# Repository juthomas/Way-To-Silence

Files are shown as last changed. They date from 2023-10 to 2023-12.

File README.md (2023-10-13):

# WAY TO SILENCE

## Goals
- Develop a module based on the ESP32, designed to read audio tracks stored on an SD card and to transmit them through a speaker output. Users should be able to adjust the parameters of these audio tracks, such as volume and balance, via an intuitive and easily accessible web interface. Furthermore, control over the tracks and playback settings via UDP signals is essential. This interface will provide users with the opportunity to customize their listening experience and adjust settings to their preferences. It will also ensure quick and efficient communication with the module through the UDP protocol. In addition, effective battery management is crucial to ensure the module's durability and optimal performance.

## 3D Render
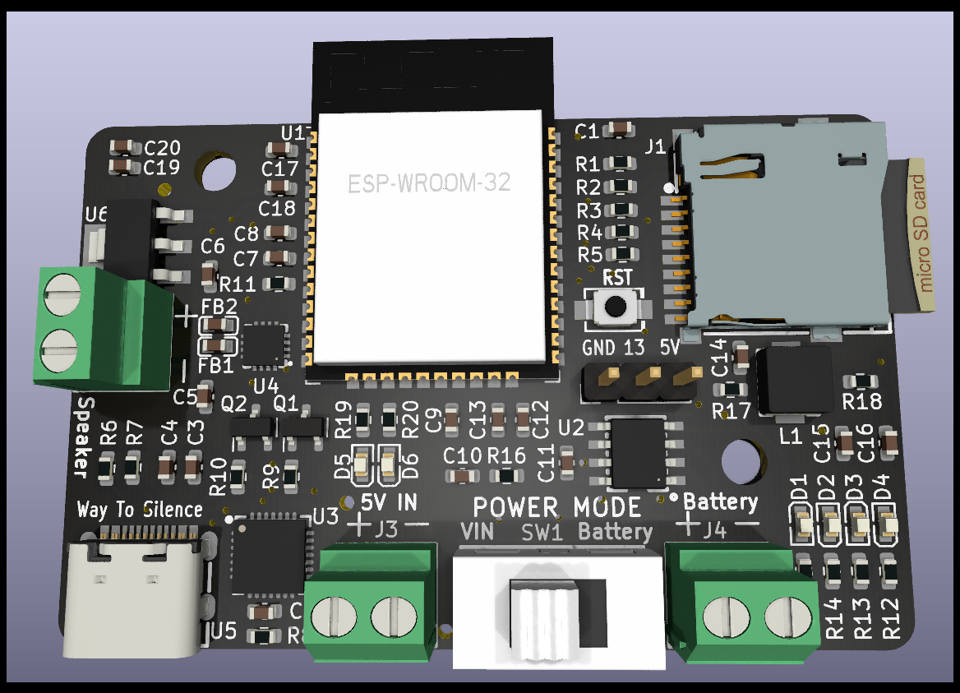
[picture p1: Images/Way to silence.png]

## Schematics

- [Link to pdf](https://github.com/juthomas/Way-To-Silence/blob/main/Schematics%20PDF/Way%20to%20silence.pdf)

## Bill Of Materials

- [Link to IBOM](https://juthomas.github.io/Way-To-Silence/)
## Components
- [I2S Amplifier Module MAX98357A](https://www.lcsc.com/product-detail/Audio-Power-OpAmps_Analog-Devices-Inc-Maxim-Integrated-MAX98357AETE-T_C910544.html) € 0.7886

- [SD Card Connector](https://jlcpcb.com/partdetail/gswitch-GT_TF003_H018502/C5155564) € 0.1553

- [ESP32 4Mb Flash](https://www.lcsc.com/product-detail/WiFi-Modules_Espressif-Systems-ESP32-WROOM-32-N4_C82899.html) € 2.5764

- [ESP32 8Mb Flash](https://www.lcsc.com/product-detail/WiFi-Modules_Espressif-Systems-ESP32-WROOM-32-N8_C529582.html) € 2.9722

- [ESP32 16Mb Flash](https://lcsc.com/product-detail/WiFi-Modules_Espressif-Systems-ESP32-WROOM-32-N16_C529581.html) € 3.3920

- [CP2102](https://www.lcsc.com/product-detail/USB-ICs_SILICON-LABS-CP2102-GMR_C6568.html) € 2.0075

- [CH340C](https://www.lcsc.com/product-detail/USB-ICs_WCH-Jiangsu-Qin-Heng-CH340C_C84681.html) € 0.45

- [BMS SM5308](https://www.lcsc.com/product-detail/Battery-Management-ICs_HICHON-SM5308_C5345582.html) € 0.2758
- [USB C Connector](https://jlcpcb.com/partdetail/Dealon-USB_TYPE_C018/C2927038) $ 0.0479
- [3.3V Regulator](https://www.lcsc.com/product-detail/Linear-Voltage-Regulators-LDO_UMW-Youtai-Semiconductor-Co-Ltd-AMS1117-3-3_C347222.html) € 0.0398

- [Bornier 3.5mm](https://www.lcsc.com/product-detail/Screw-terminal_Ningbo-Xinlaiya-Elec-XY350V-3-5-2P_C784942.html) € 0.1065
- [2.2uH Inductance](https://www.lcsc.com/product-detail/Inductors-SMD_KOHERelec-MDA4020-2R2M_C2847469.html) € 0.7154
- [1uH Inductance](https://www.lcsc.com/product-detail/Inductors-SMD_KOHERelec-MDA4020-1R0M_C2847468.html#) € 0.7287
- [Battery Switch](https://jlcpcb.com/partdetail/XkbConnectivity-SS12D10L3/C319013) € 0.8814
- [Reset Button](https://jlcpcb.com/partdetail/Xunpu-TS_1088R02026/C455280) € 0.0448

- [4.7nF Capacitor](https://jlcpcb.com/partdetail/55004-0603B472K500NT/C53987) € 0.0025
- [4.7uF Capacitor](https://jlcpcb.com/partdetail/20375-CL10A475KO8NNNC/C19666) € 0.0095
- [10uF Capacitor](https://jlcpcb.com/partdetail/MurataElectronics-GRM188R60J106ME47D/C77041) € 0.0085	
- [22uF Capacitor](https://jlcpcb.com/partdetail/60514-CL10A226MQ8NRNC/C59461) € 0.0085
- [100nF Capacitor](https://jlcpcb.com/partdetail/Yageo-CC0603KRX7R9BB104/C14663) € 0.0022
- [220pF Capacitor](https://jlcpcb.com/partdetail/1955-CL10B221KB8NNNC/C1603) € 0.0055
- [0Ω Resistor](https://jlcpcb.com/partdetail/21903-0603WAF0000T5E/C21189) € 0.0011
- [100mΩ Resistor](https://jlcpcb.com/partdetail/112253-0603WAF100LT5E/C111027) € 0.0039
- [500mΩ Resistor](https://jlcpcb.com/partdetail/Fojan-FRL0603FR500TS/C2934253) € 0.0031
- [1Ω Resistor](https://jlcpcb.com/partdetail/25955-0603WAJ010JT5E/C25212) € 0.0009
- [1kΩ Resistor](https://jlcpcb.com/partdetail/21904-0603WAF1001T5E/C21190) € 0.0006

- [5.11kΩ Resistor](https://jlcpcb.com/partdetail/419038-TC0350B5111T5E/C425414) € 0.0167
- [10kΩ Resistor](https://jlcpcb.com/partdetail/26547-0603WAF1002T5E/C25804) € 0.0009
- [1MΩ Resistor](https://jlcpcb.com/partdetail/23662-0603WAF1004T5E/C22935) € 0.0011
- [Red LED](https://jlcpcb.com/partdetail/85432-NCD0603R1/C84263) € 0.0078
- [Yellow LED](https://jlcpcb.com/partdetail/85437-NCD0603Y1/C84268) € 0.0111
- [Ferrite Bead](https://jlcpcb.com/partdetail/373749-CBW160808U470T/C394474) € 0.0030
- [Transistor](https://jlcpcb.com/partdetail/Shikues-BC817/C475629) € 0.0150

## Tools used

- [KiCad](https://www.kicad.org/)
- [KiCad Fabrication Toolkit Plugin](https://github.com/bennymeg/JLC-Plugin-for-KiCad)
- [KiCad Interactive Html Bom Plugin](https://github.com/openscopeproject/InteractiveHtmlBom)
- [LCSC](https://www.lcsc.com/)
- [JCLPCB](https://jlcpcb.com/)

- [EasyEDA to KiCad](https://wokwi.com/tools/easyeda2kicad)

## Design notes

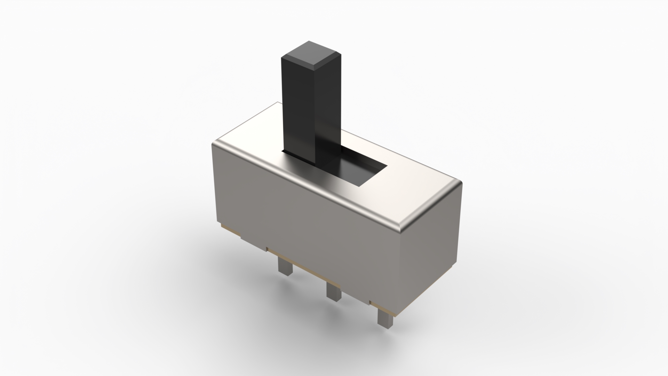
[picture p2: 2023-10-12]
3D Models/Switch/Untitled Project.jpg

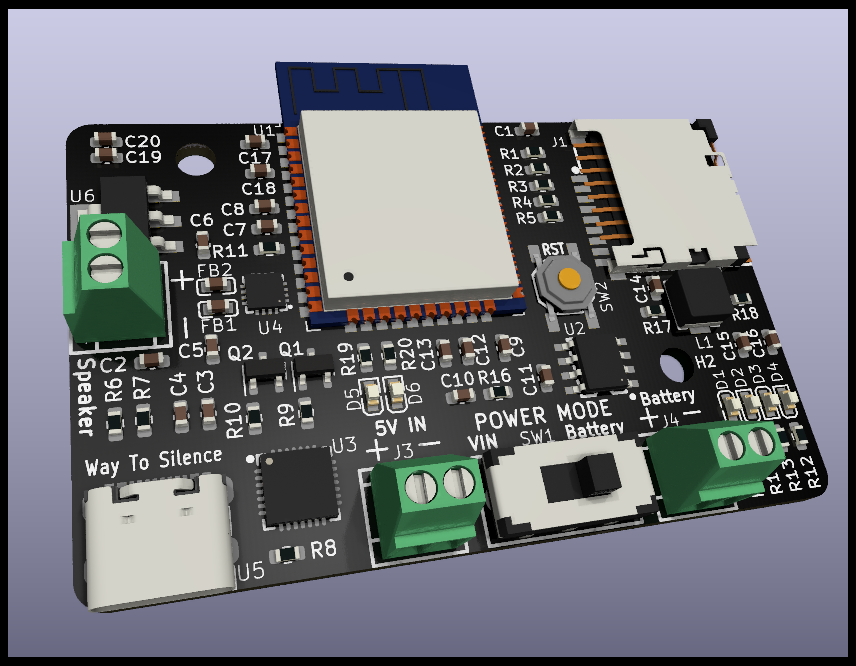
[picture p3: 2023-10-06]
Way to silence/Way to silence, Non-routed.png

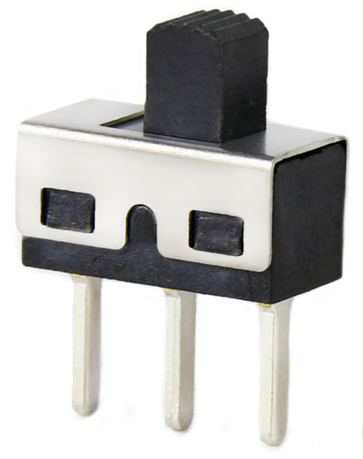
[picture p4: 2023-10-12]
3D Models/Switch Button/SS-12D10.png

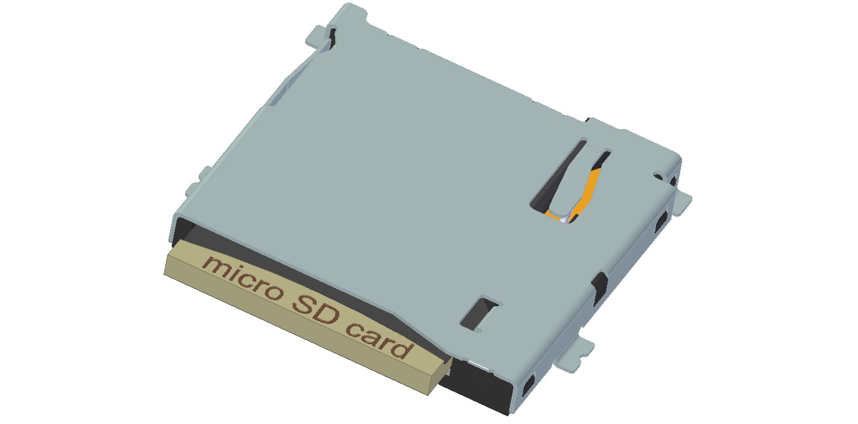
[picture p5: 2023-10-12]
3D Models/Micro SD/Micro_SD_Card_and_Holder.jpg

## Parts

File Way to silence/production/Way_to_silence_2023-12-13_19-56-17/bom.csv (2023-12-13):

Designator | Footprint | Quantity | Value | LCSC Part #
C1, C18, C19, C2, C3, C7 | 0603 | 6 | 100nF | C14663
C10, C12, C17, C20, C21, C8, C9 | 0603 | 7 | 10uF | C77041
C11, C16 | 0603 | 2 | 22uF | C59461
C4 | 0603 | 1 | 4.7uF | C19666
C5, C6 | 0603 | 2 | 220pF | C1603
D1, D2, D3, D4, D5, D6 | LED_0603 | 6 | LED | C84268
FB1, FB2 | FB_0603 | 2 | FerriteBead | C394474
J1 | SD_Card_Connector | 1 | SD Card Connector | C5155564
J2 | Screw_Terminal_3.5 | 1 | Amplificator_Terminal | C784942
J3 | Screw_Terminal_3.5 | 1 | 5V_Terminal | C784942
J4 | Screw_Terminal_3.5 | 1 | Battery_Terminal | C784942
J6 | PinHeader_1x04_P2.54mm_Vertical | 1 | Conn_01x04_Pin
L1 | Inductor-0630LR | 1 | 2.2UH | C5189746
Q1, Q2 | SOT-23 | 2 | BC817 | C475629
R1, R10, R17, R2, R21, R3, R4, R5, R9 | 0603 | 9 | 10K | C25804
R11, R8 | 0603 | 2 | 1M | C22935
R12, R13, R14, R15 | 0603 | 4 | 0 | C21189
R16 | 0603 | 1 | 1R | C25212
R19, R20 | 0603 | 2 | 1K | C21190
R6, R7 | 0603 | 2 | 5.11K | C425414
SW1 | SW_SPDT | 1 | SW_SPDT | C319013
SW2, SW3 | SW_SPST | 2 | SW_SPST | C455280
U1 | ESP32-WROOM-32 | 1 | ESP32-WROOM-32-N16 | C529581
U2 | SM5308 | 1 | SM5308 | C5345582
U3 | CP2102 | 1 | CP2102-GMR | C6568
U4 | MAX98357 | 1 | MAX98357AETE+T | C910544
U5 | USB_C_Receptacle | 1 | USB-TYPE-C-018 | C2927038
U6 | AMS1117CD-3.3 | 1 | AMS1117CD-3.3 | C347222

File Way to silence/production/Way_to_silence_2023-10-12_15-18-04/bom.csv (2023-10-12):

Designator | Footprint | Quantity | Value | LCSC Part #
C1, C18, C19, C2, C3, C7 | 0603 | 6 | 100nF | C14663
C10, C17, C20, C8, C9 | 0603 | 5 | 10uF | C77041
C11, C12, C13, C15, C16 | 0603 | 5 | 22uF | C59461
C14 | 0603 | 1 | 4.7nF | C53987
C4 | 0603 | 1 | 4.7uF | C19666
C5, C6 | 0603 | 2 | 220pF | C1603
D1, D2, D3, D4, D5, D6 | LED_0603 | 6 | LED | C84268
FB1, FB2 | FB_0603 | 2 | FerriteBead | C394474
J1 | SD_Card_Connector | 1 | SD Card Connector | C5155564
J2 | Screw_Terminal_3.5 | 1 | Amplificator_Terminal | C784942
J3 | Screw_Terminal_3.5 | 1 | 5V_Terminal | C784942
J4 | Screw_Terminal_3.5 | 1 | Battery_Terminal | C784942
J5 | PinHeader_1x03_P2.54mm_Vertical | 1 | LEDS Port
L1 | Inductor | 1 | 1UH | C2847468
Q1, Q2 | SOT-23 | 2 | BC817 | C475629
R1, R10, R2, R3, R4, R5, R9 | 0603 | 7 | 10K | C25804
R11, R8 | 0603 | 2 | 1M | C22935
R12, R13, R14, R15 | 0603 | 4 | 0 | C21189
R16 | 0603 | 1 | 0.5R | C2934253
R17 | 0603 | 1 | 1R | C25212
R18 | 0603 | 1 | 0.1R | C111027
R19, R20 | 0603 | 2 | 1K | C21190
R6, R7 | 0603 | 2 | 5.11K | C425414
SW1 | SW_SPDT | 1 | SW_SPDT | C319013
SW3 | SW_SPST | 1 | SW_SPST | C455280
U1 | ESP32-WROOM-32 | 1 | ESP32-WROOM-32-N16 | C529581
U2 | SM5308 | 1 | SM5308 | C5345582
U3 | CP2102 | 1 | CP2102-GMR | C6568
U4 | MAX98357 | 1 | MAX98357AETE+T | C910544
U5 | USB_C_Receptacle | 1 | USB-TYPE-C-018 | C2927038
U6 | AMS1117CD-3.3 | 1 | AMS1117CD-3.3 | C347222

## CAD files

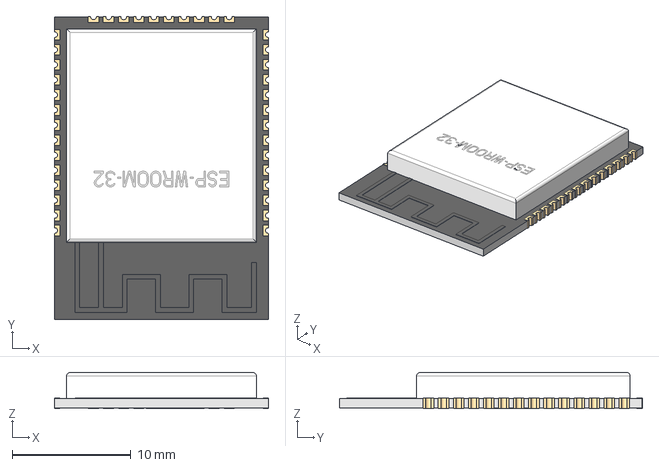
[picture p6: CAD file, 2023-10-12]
3D Models/ESP 32/KiCAD-ESP-WROOM-32.step
18.1 x 25.5 x 3.04 mm

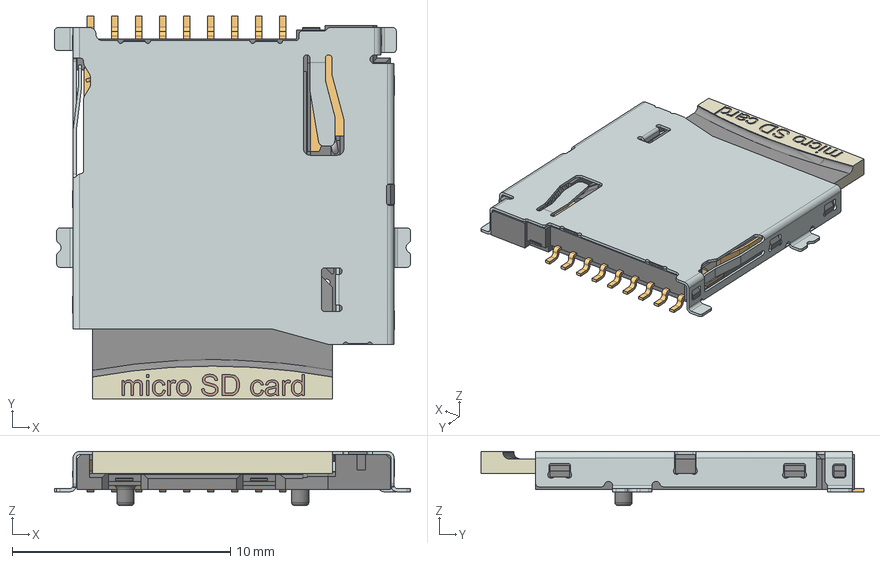
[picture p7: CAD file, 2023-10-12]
3D Models/Micro SD/Micro_SD_Card_and_Holder.stp
16.3 x 17.5 x 2.48 mm
693071020811_Housing
693071020811_Guide
693071020811_Spring
693071020811_Contact
693071020811_Hook
693071020811_Agraphe
693071020811_Shielding
MicroSD

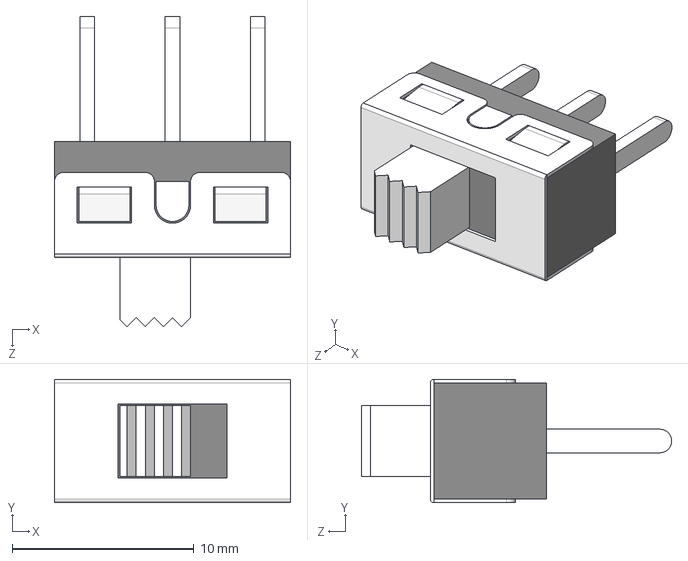
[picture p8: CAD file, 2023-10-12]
3D Models/Switch Button/SS-12D10L4.STEP
13.0 x 6.80 x 17.1 mm

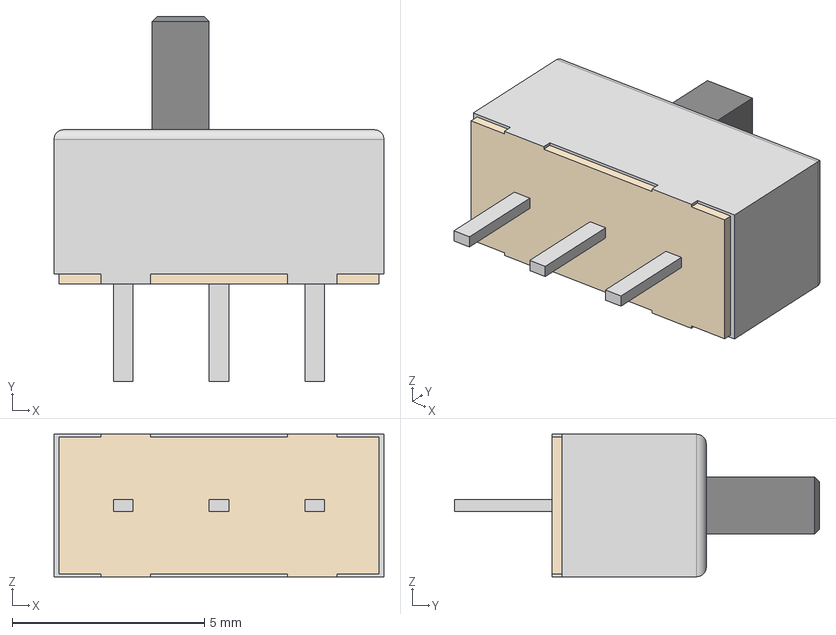
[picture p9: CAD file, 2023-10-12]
3D Models/Switch/Selector Switch - SS12D00.stp
8.59 x 9.50 x 3.71 mm

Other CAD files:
3D Models/Switch Button/SS-12D10L4.SLDPRT
3D Models/Switch/Selector Switch - SS12D00.SLDPRT

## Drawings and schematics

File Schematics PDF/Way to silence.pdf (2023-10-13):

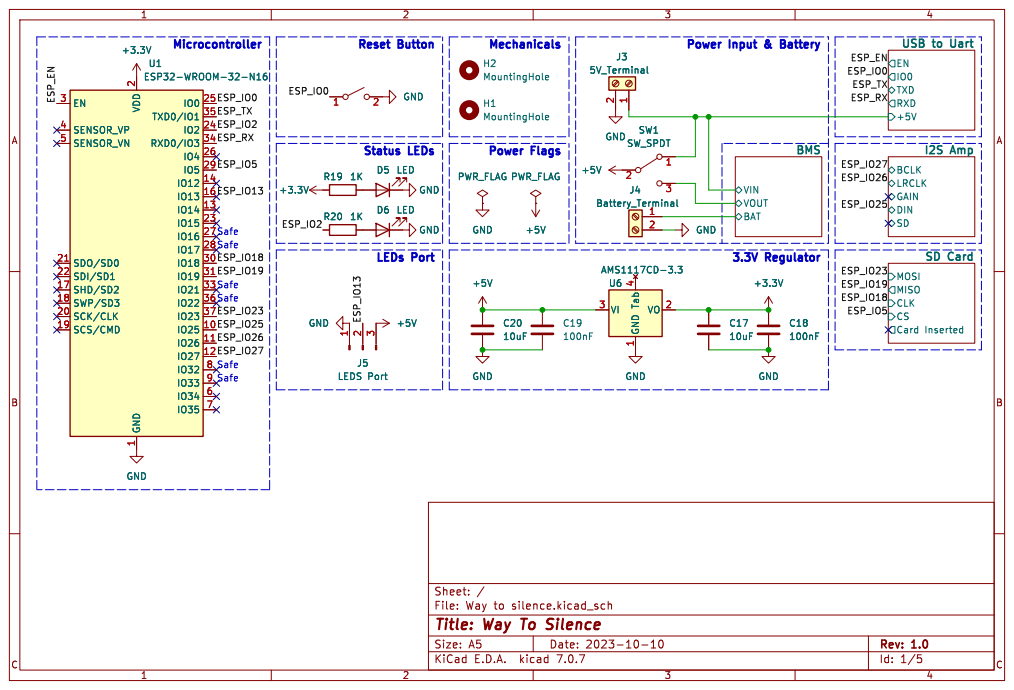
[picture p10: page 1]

2 SCK/CLK 20 SDO/SD0 21 SDI/SD1 22

Card Inserted CSCLK MOSI SD Card

Id: 1/5 Title: Way To Silence

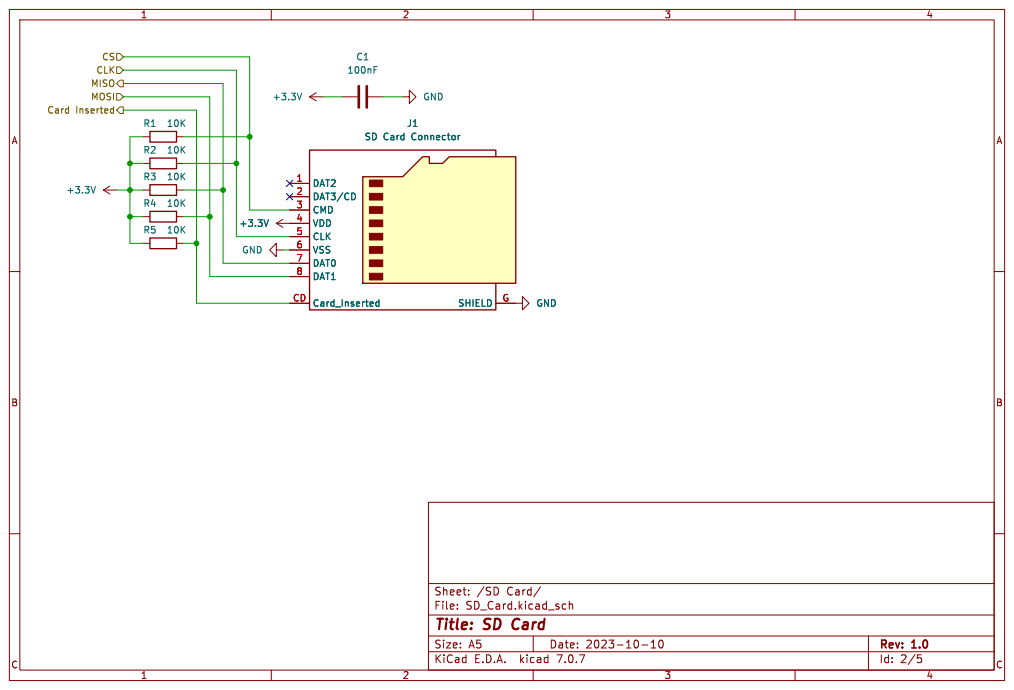
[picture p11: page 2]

J1 SD Card Connector MISO

Id: 2/5 Title: SD Card

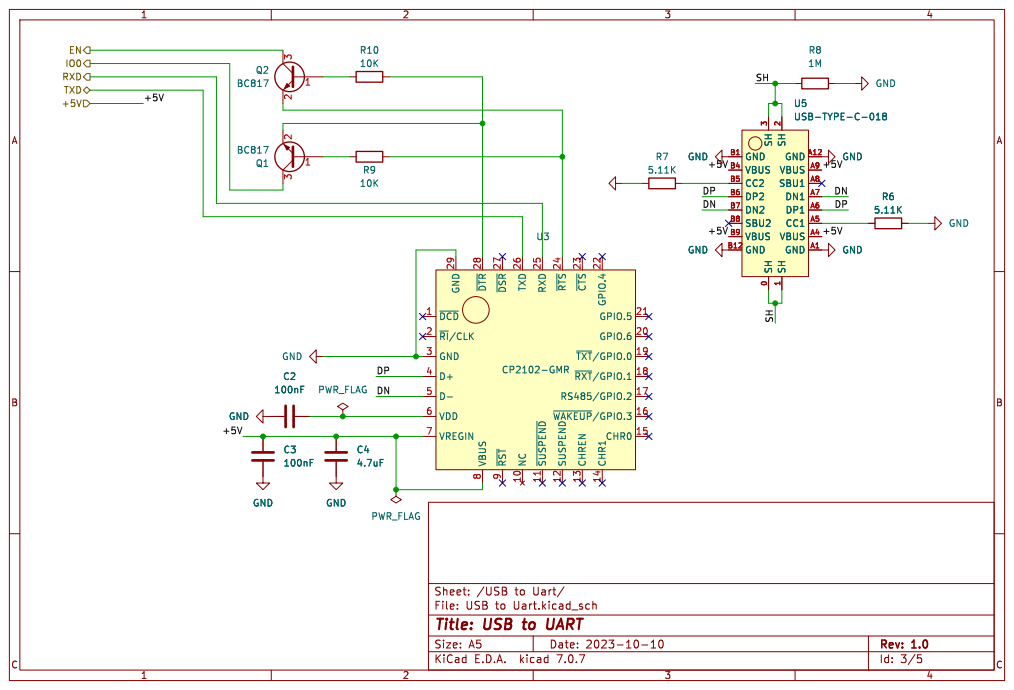
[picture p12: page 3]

3 GND A1 GND A12 VBUS A4 CC1 A5 DP1 A6 DN1 A7 SBU1 A8 VBUS A9 GND B1 GND B12 VBUS B4 CC2 B5 DP2 B6 DN2 B7 SBU2 B8 VBUS B9 U5 USB-TYPE-C-018 GND GND

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

Id: 3/5 Title: USB to UART

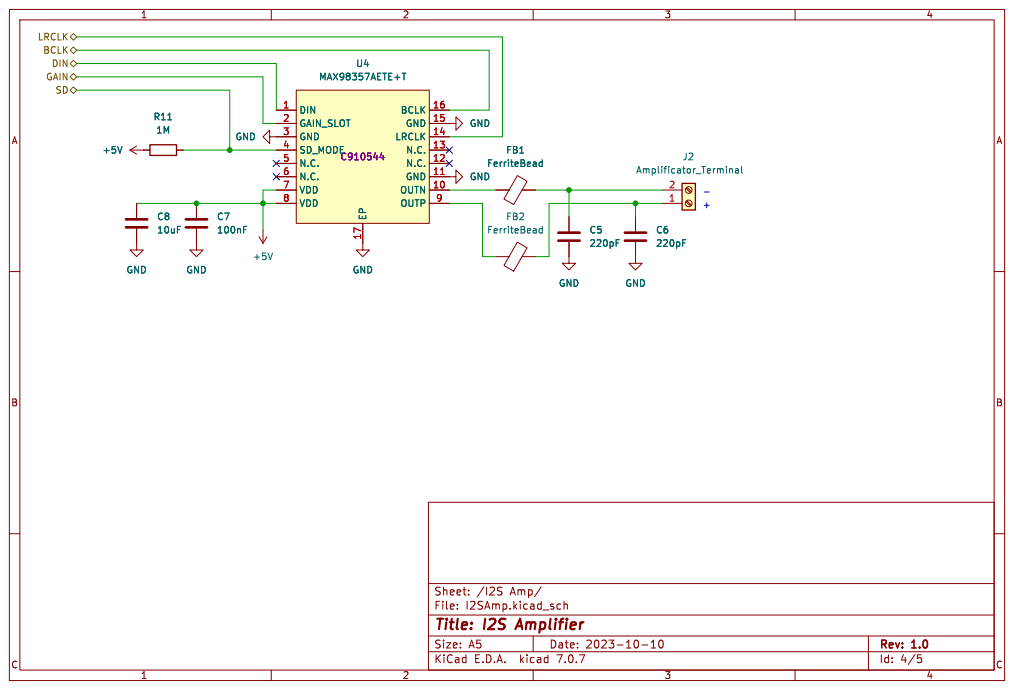
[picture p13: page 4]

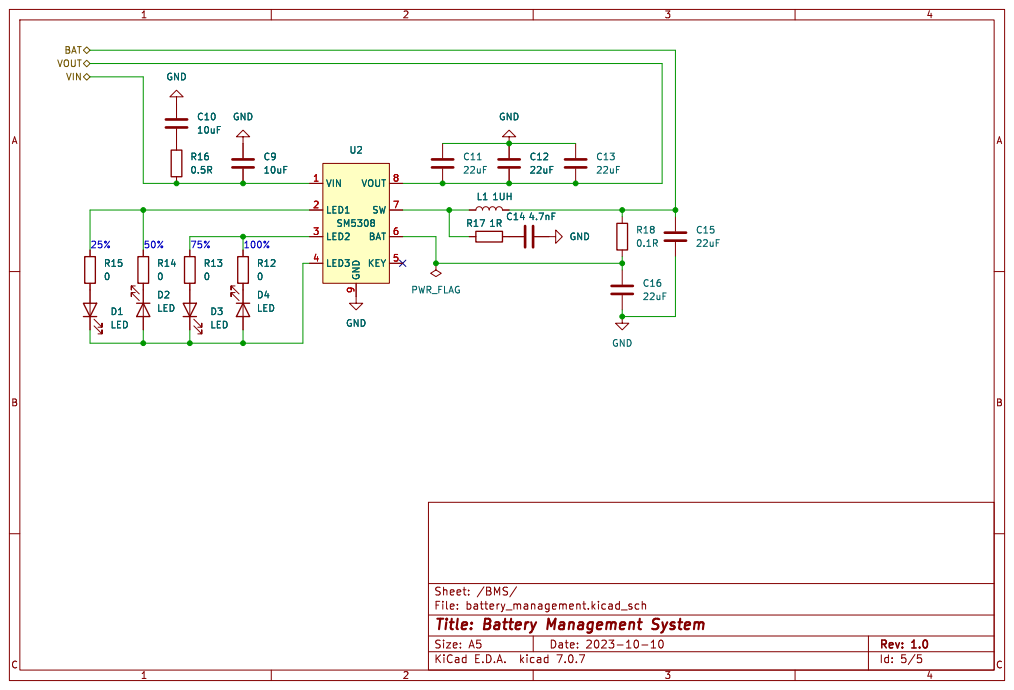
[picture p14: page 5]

Id: 5/5 Title: Battery Management System

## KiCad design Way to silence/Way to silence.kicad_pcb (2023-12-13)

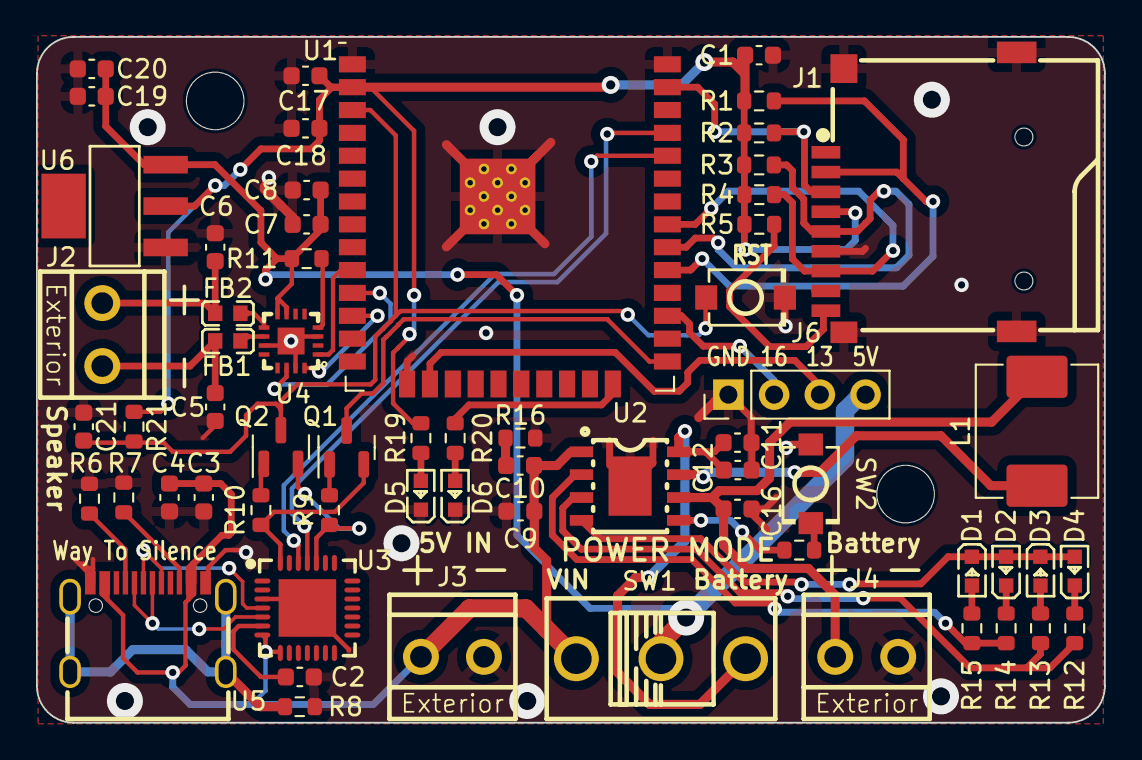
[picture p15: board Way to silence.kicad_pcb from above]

Board: 2 copper layers, 59.3 x 38.1 mm, 65 parts (0 on the bottom side), 49 nets.

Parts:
C1, C2, C3, C7, C18, C19: 100nF; C_0603_1608Metric
C4: 4.7uF; C_0603_1608Metric
C5, C6: 220pF; C_0603_1608Metric
C8, C9, C10, C12, C17, C20, C21: 10uF; C_0603_1608Metric
C11, C16: 22uF; C_0603_1608Metric
D1, D2, D3, D4, D5, D6: LED; LED_0603
FB1, FB2: FerriteBead; FB_0603
H1, H2: MountingHole; MountingHole_3.2mm_M3
J1: SD Card Connector; SD_Card_Connector
J2: Amplificator_Terminal; Screw_Terminal_3.5
J3: 5V_Terminal; Screw_Terminal_3.5
J4: Battery_Terminal; Screw_Terminal_3.5
J6: Conn_01x04_Pin; PinHeader_1x04_P2.54mm_Vertical
L1: 2.2UH; Inductor-0630LR
Q1, Q2: BC817; SOT-23
R1, R2, R3, R4, R5, R9, R10, R17, R21: 10K; R_0603_1608Metric
R6, R7: 5.11K; R_0603_1608Metric
R8, R11: 1M; R_0603_1608Metric
R12, R13, R14, R15: 0; R_0603_1608Metric
R16: 1R; R_0603_1608Metric
R19, R20: 1K; R_0603_1608Metric
SW1: SW_SPDT
SW2, SW3: SW_SPST
U1: ESP32-WROOM-32-N16; ESP32-WROOM-32
U2: SM5308
U3: CP2102-GMR; CP2102
U4: MAX98357AETE+T; MAX98357
U5: USB-TYPE-C-018; USB_C_Receptacle
U6: AMS1117CD-3.3

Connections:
+3.3V: C1.1, C17.2, C18.2, J1.4 (VDD), R1.1, R2.1, R3.1, R4.1, R5.1, R19.2, R21.1, U1.2 (VDD), U6.2 (VO)
+5V: C7.2, C8.2, C19.2, C20.2, J6.4, R11.1, SW1.2 (B), U4.7 (VDD), U4.8 (VDD), U6.3 (VI)
/BMS/BAT: C16.2, J4.1, L1.2, U2.6 (BAT)
/BMS/VOUT: C11.1, C12.1, SW1.3 (C), U2.8 (VOUT)
/ESP_EN: C21.2, Q2.3 (C), R21.2, SW3.1 (A), U1.3 (EN)
/ESP_IO0: Q1.3 (C), U1.25 (IO0)
/ESP_IO2: R20.2, U1.24 (IO2)
/ESP_IO5: J1.2 (DAT3/CD), R1.2, U1.29 (IO5)
/ESP_IO13: J6.3, U1.16 (IO13)
/ESP_IO16: J6.2, U1.27 (IO16)
/ESP_IO18: J1.5 (CLK), R3.2, U1.30 (IO18)
/ESP_IO19: J1.7 (DAT0), R4.2, U1.31 (IO19)
/ESP_IO23: J1.3 (CMD), R2.2, U1.37 (IO23)
/ESP_IO25: U1.10 (IO25), U4.1 (DIN)
/ESP_IO26: U1.11 (IO26), U4.14 (LRCLK)
/ESP_IO27: U1.12 (IO27), U4.16 (BCLK)
/ESP_RX: U1.34 (RXD0/IO3), U3.26 (TXD)
/ESP_TX: U1.35 (TXD0/IO1), U3.25 (RXD)
/I2S Amp/SD: R11.2, U4.4 (SD_MODE)
/SD Card/Card Inserted: J1.CD (Card_Inserted), R5.2
/USB to Uart/+5V: C3.2, C4.2, C9.1, C10.1, J3.1, SW1.1 (A), U2.1 (VIN), U3.7 (VREGIN), U3.8 (VBUS), U5.A4 (VBUS), U5.A9 (VBUS), U5.B4 (VBUS), U5.B9 (VBUS)
/USB to Uart/DN: U3.5 (D-), U5.A7 (DN1), U5.B7 (DN2)
/USB to Uart/DP: U3.4 (D+), U5.A6 (DP1), U5.B6 (DP2)
/USB to Uart/SH: R8.1, U5.0 (SH), U5.1 (SH), U5.2 (SH), U5.3 (SH)
GND: C1.2, C2.1, C3.1, C4.1, C5.1, C6.1, C7.1, C8.1, C9.2, C11.2, C12.2, C16.1, C17.1, C18.1, C19.1, C20.1, C21.1, D5.1 (K), D6.1 (K), J1.6 (VSS), J1.G (SHIELD), J3.2, J4.2, J6.1, R6.2, R7.1, R8.2, R16.2, SW2.1 (A), SW3.2 (B), U1.1 (GND), U1.15 (GND), U1.38 (GND), U1.39 (GND), U2.9 (GND), U3.3 (GND), U3.29 (GND), U4.3 (GND), U4.11 (GND), U4.15 (GND), U4.17 (EP), U5.A1 (GND), U5.A12 (GND), U5.B1 (GND), U5.B12 (GND), U6.1 (GND)
unnamed: C10.2, R16.1
unnamed: D1.2 (A), R15.1
unnamed: D1.1 (K), D2.2 (A), D3.1 (K), D4.2 (A), U2.4 (LED3)
unnamed: D2.1 (K), R14.1
unnamed: D3.2 (A), R13.1
unnamed: D4.1 (K), R12.1
unnamed: D5.2 (A), R19.1
unnamed: D6.2 (A), R20.1
unnamed: C6.2, FB2.2, J2.1
unnamed: C5.2, FB1.2, J2.2
unnamed: Q1.1 (B), R9.2
unnamed: Q1.2 (E), R10.1, U3.28 (~DTR)
unnamed: Q2.1 (B), R10.2
unnamed: Q2.2 (E), R9.1, U3.24 (~RTS)
unnamed: R17.1, SW2.2 (B)
unnamed: R17.2, U2.5 (KEY)
unnamed: R14.2, R15.2, U2.2 (LED1)
unnamed: R12.2, R13.2, U2.3 (LED2)
unnamed: L1.1, U2.7 (SW)
unnamed: C2.2, U3.6 (VDD)
unnamed: FB1.1, U4.10 (OUTN)
unnamed: FB2.1, U4.9 (OUTP)
unnamed: R6.1, U5.A5 (CC1)
unnamed: R7.2, U5.B5 (CC2)

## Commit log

2023-10-02 [ADD] SD Card Sheet
    [SD_Card.kicad_sch, Way to silence.kicad_sch]
2023-10-02 [DRC] Working on SD Sheet
    [SD_Card.kicad_sch, Way to silence.kicad_sch]
2023-10-02 [UDPT] Changed pulled down to pulled up
    [SD_Card.kicad_sch]
2023-10-02 [ADD] USB To Uart Sheet
    [USB to Uart.kicad_sch, Way to silence.kicad_sch]
2023-10-02 [ADD] USB C Connections
    [SD_Card.kicad_sch, USB to Uart.kicad_sch, Way to silence.kicad_sch]
2023-10-03 [DRC] Working on USB to UART Sheet
    [USB to Uart.kicad_sch, Way to silence.kicad_sch]
2023-10-03 [ADD] I2S AMP Sheet
    [I2SAmp.kicad_sch, Way to silence.kicad_sch]
2023-10-03 [ADD] Screw Connector
    [I2SAmp.kicad_sch]
2023-10-03 [DRC] I2S Amp seems Sheet ok
    [I2SAmp.kicad_sch, Way to silence.kicad_sch]
2023-10-03 [ADD] BMS Sheet
    [Way to silence.kicad_sch, battery_management.kicad_sch]
2023-10-04 [DRC] Working on BMS Sheet
    [Way to silence.kicad_sch, battery_management.kicad_sch]
2023-10-04 [ADD] Completed some connections in main sheet
    [USB to Uart.kicad_sch, Way to silence.kicad_sch]
2023-10-05 [ADD] 3v3 Reg
    [USB to Uart.kicad_sch, Way to silence.kicad_sch]
2023-10-06 [DRC] No errors
    [Way to silence.kicad_sch]
2023-10-06 [ADD] New reg footprint and datasheet
    [USB to Uart.kicad_sch, Way to silence.kicad_sch]
2023-10-06 [ADD] LSCS Parts and Footprints for BMS
    [I2SAmp.kicad_sch, SD_Card.kicad_sch, USB to Uart.kicad_sch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]
2023-10-06 [ADD] References in readme
    [I2SAmp.kicad_sch, Way to silence.kicad_sch, battery_management.kicad_sch]
2023-10-06 [UPDT] Switch source
    [I2SAmp.kicad_sch, Way to silence.kicad_sch]
2023-10-06 [ADD] I2S Amp LSCS Refs
    [I2SAmp.kicad_sch]
2023-10-06 [ADD] LCSC References
    [USB to Uart.kicad_sch]
2023-10-06 [ADD] SD Card LCSC Refs
    [SD_Card.kicad_sch]
2023-10-06 [ADD] Inductor references
    [Way to silence.kicad_sch, battery_management.kicad_sch]
2023-10-06 [ADD] Footprints for connectors
    [Way to silence.kicad_pcb, Way to silence.kicad_sch]
2023-10-06 [ADD] Missing footprints
    [I2SAmp.kicad_sch, Way to silence.kicad_pcb]
2023-10-06 [ADD] Beg of routing
    [I2SAmp.kicad_sch, Way to silence.kicad_pcb]
2023-10-06 [ADD] i2S Module placed
    [I2SAmp.kicad_sch, Way to silence.kicad_pcb]
2023-10-06 [ADD] Routing placement seems ok
    [Way to silence.kicad_pcb]
2023-10-06 [ADD] Placement adjustements
    [Way to silence.kicad_pcb]
2023-10-06 [ADD] 3d Models
    [Way to silence.kicad_pcb]
2023-10-06 [ADD] Board Shape ok
    [Way to silence.kicad_pcb]
2023-10-06 [ADD] Update for mounting holes
    [Way to silence.kicad_pcb, Way to silence.kicad_sch]
2023-10-09 [FIX] DRC and replacing button
    [I2SAmp.kicad_sch, Way to silence.kicad_pcb, Way to silence.kicad_sch]
2023-10-09 [ADD] Pin header for leds
    [Way to silence.kicad_pcb]
2023-10-10 [ADD] Styles to shematics
    [USB to Uart.kicad_sch, Way to silence.kicad_pcb, Way to silence.kicad_sch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]
2023-10-10 [ADD] Root page style
    [Way to silence.kicad_sch]
2023-10-10 [ADD] Shematics files settings
    [I2SAmp.kicad_sch, SD_Card.kicad_sch, USB to Uart.kicad_sch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]
2023-10-10 [ERC] 1 Warning cleaned
    [USB to Uart.kicad_sch, Way to silence.kicad_sch]
2023-10-10 [UDPT] Leds colors
    [Way to silence.kicad_pcb, Way to silence.kicad_sch, battery_management.kicad_sch]
2023-10-10 [UDPT] Sheet name
    [Way to silence.kicad_sch]
2023-10-10 [UDPT] Text sizes in footprints
    [Way to silence.kicad_pcb]
2023-10-10 [RTN] Routing in progress
    [Way to silence.kicad_pcb]
2023-10-11 [RTN] Non gnd completed
    [Way to silence.kicad_pcb]
2023-10-11 [UDPT] Page Settings
    [Way to silence.kicad_pcb]
2023-10-11 [DRC] Seems ok
    [Way to silence.kicad_pcb]
2023-10-11 [ADD] Back Silkscreen
    [Way to silence.kicad_pcb]
2023-10-11 [ADD] Qr code & website
    [Way to silence.kicad_pcb]
2023-10-12 [FIX] Error in shematics
    [USB to Uart.kicad_sch]
2023-10-12 [FIX] LCSC Parts property
    [I2SAmp.kicad_sch, USB to Uart.kicad_sch, Way to silence.kicad_pcb]
2023-10-12 [ADD] Terminals Rotations
    [I2SAmp.kicad_sch, Way to silence.kicad_pcb, Way to silence.kicad_sch]
2023-10-12 [ADD] U6 Q1 Q2 Rotations
    [USB to Uart.kicad_sch, Way to silence.kicad_pcb, Way to silence.kicad_sch]
2023-10-12 [ADD] ESP32 Position file
    [Way to silence.kicad_pcb, Way to silence.kicad_sch, bom.csv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]
2023-10-12 [ADD] Better 3D models
    [I2SAmp.kicad_sch, KiCAD-ESP-WROOM-32.step, Micro_SD_Card_and_Holder.stp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]
2023-10-12 [DRC] No warnings, no errors
    [Way to silence.kicad_pcb]
2023-10-13 [ADD] 3D View + Schematics PDF
2023-11-17 [ADD] First design fixes
    [SD_Card.kicad_sch, USB to Uart.kicad_sch]
2023-11-20 [ADD] Notes to update design
    [USB to Uart.kicad_sch]
2023-11-20 [ADD] Notes to update design (RST problem)
    [Way to silence.kicad_sch]
2023-11-30 [UDPT] Schematics from testings
    [SD_Card.kicad_sch, USB to Uart.kicad_sch, Way to silence.kicad_sch]
2023-11-30 [UDPT] Pcb from schematics
    [Way to silence.kicad_pcb]
2023-11-30 [ADD] IO port
    [Way to silence.kicad_pcb, Way to silence.kicad_sch]
2023-11-30 [ADD] Retro-engineering BMS notes
    [battery_management.kicad_sch]
2023-11-30 [UDPT] Schematics from retro-engineering
    [battery_management.kicad_sch]
2023-12-13 [CLEAN] Remove retro-engineering drawing
    [Way to silence.kicad_pcb, Way to silence.kicad_sch, battery_management.kicad_sch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]
